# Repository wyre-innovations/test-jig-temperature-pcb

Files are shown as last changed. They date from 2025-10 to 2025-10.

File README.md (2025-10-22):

# STM32G0-based Temperature Test Jig PCB

This repository contains the design and manufacturing files for a temperature test jig PCB based on the STM32G0 microcontroller, featuring a 16×2 LCD and 8 thermistor sensors.

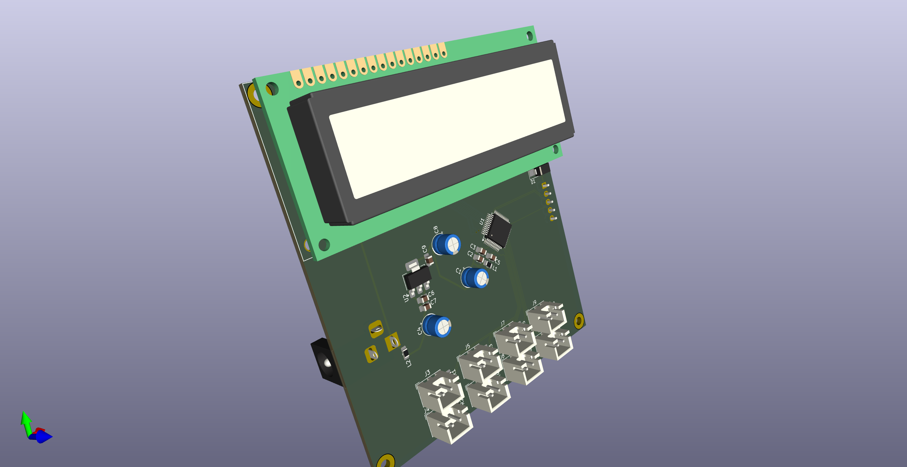
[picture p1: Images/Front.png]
Front View


### Project Structure

The project is organized into the following directories:

- `Design/`: Contains the KiCad design files.
    - `test-jig-temperature-pcb.kicad_pcb`: PCB layout file.
    - `test-jig-temperature-pcb.kicad_pro`: Project file.
    - `test-jig-temperature-pcb.kicad_sch`: Schematic file.
- `Docs/`: Documentation for the project.
    - `Schematic.pdf`: PDF version of the schematic.
- `Images/`: Images related to the project.
    - `Front.png`: Front view image.

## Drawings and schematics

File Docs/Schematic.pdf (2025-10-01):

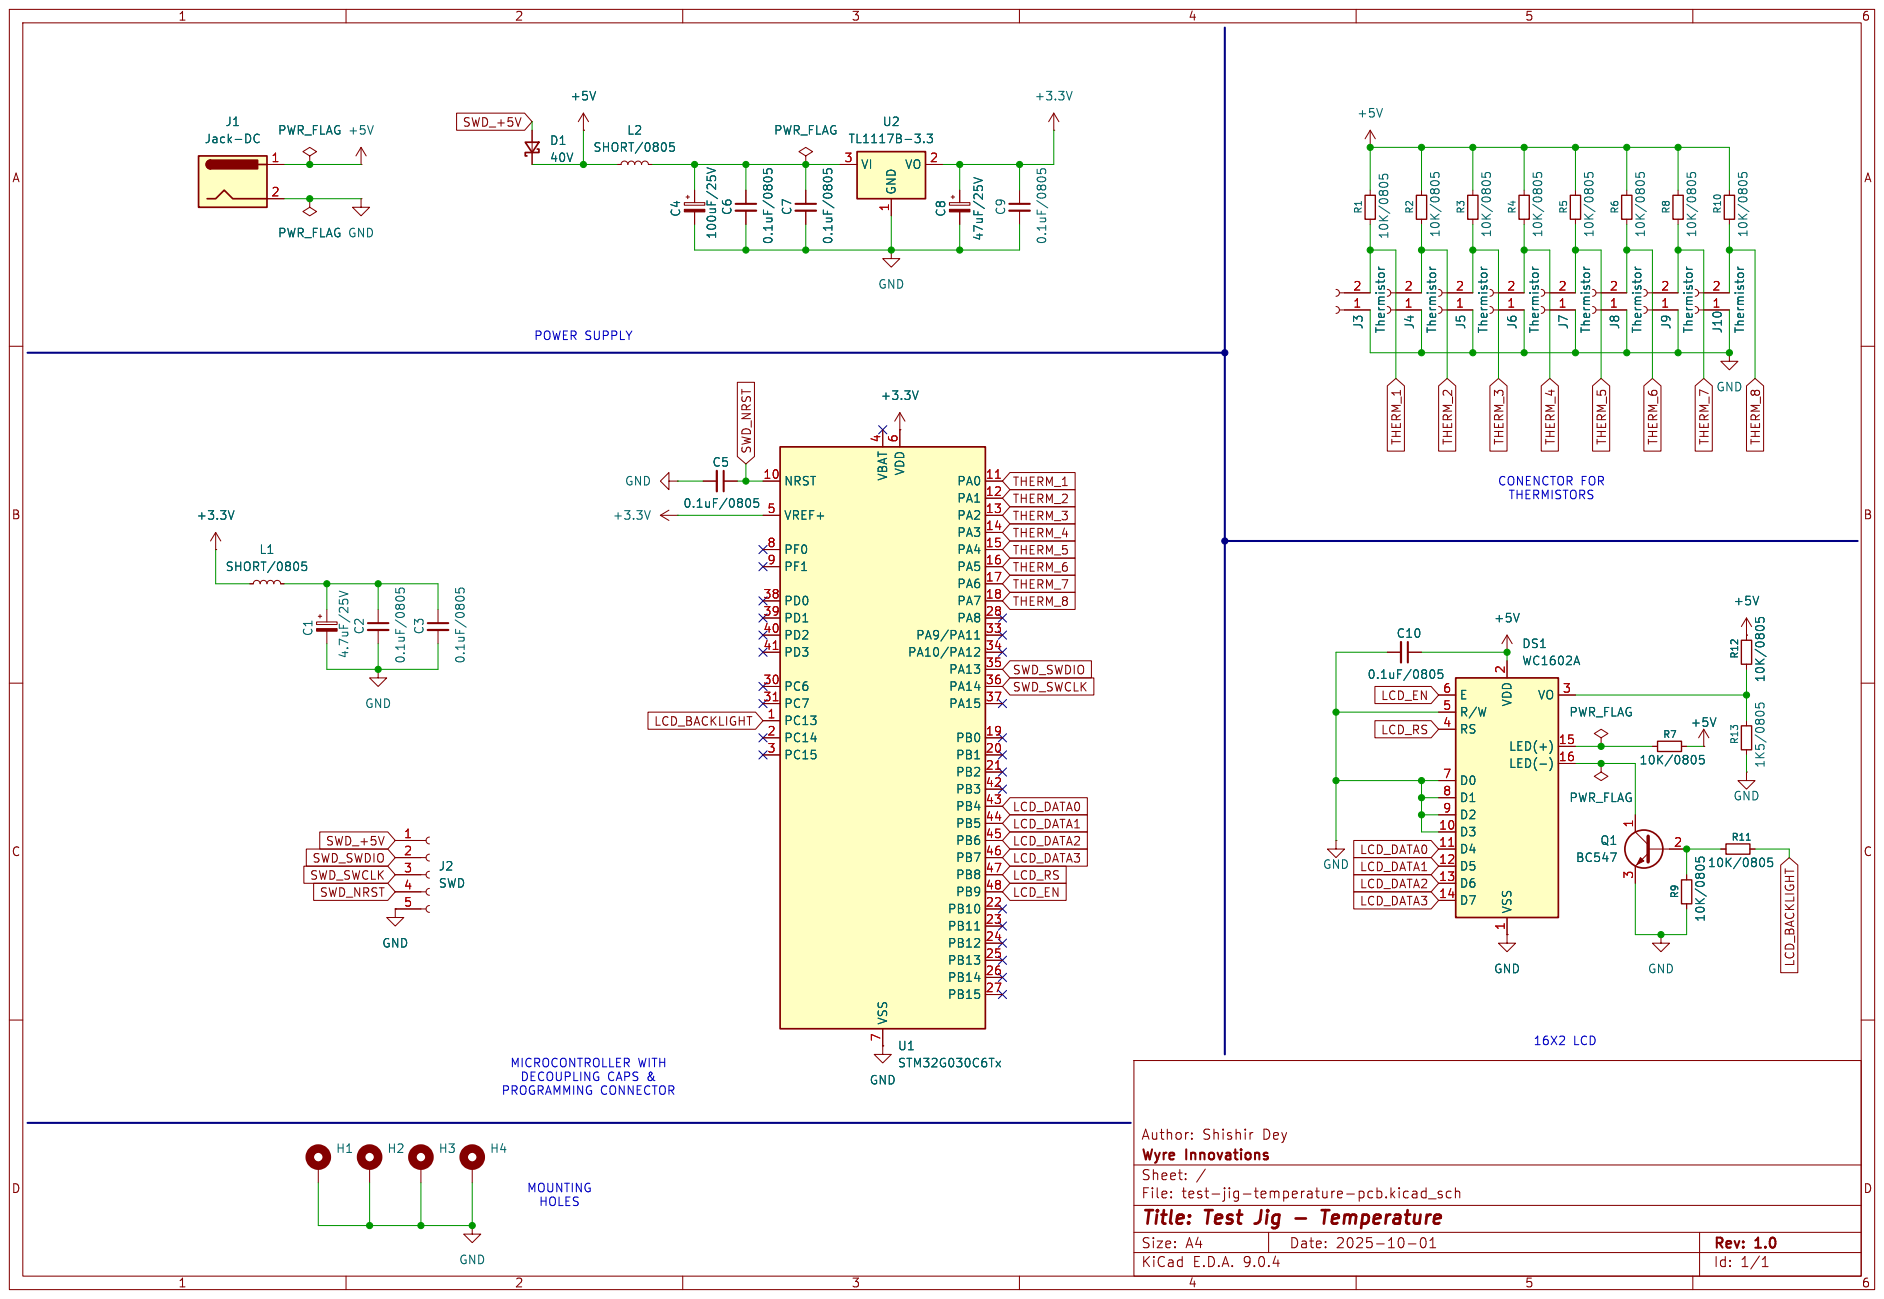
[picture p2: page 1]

Id: 1/1 Title: Test Jig - Temperature

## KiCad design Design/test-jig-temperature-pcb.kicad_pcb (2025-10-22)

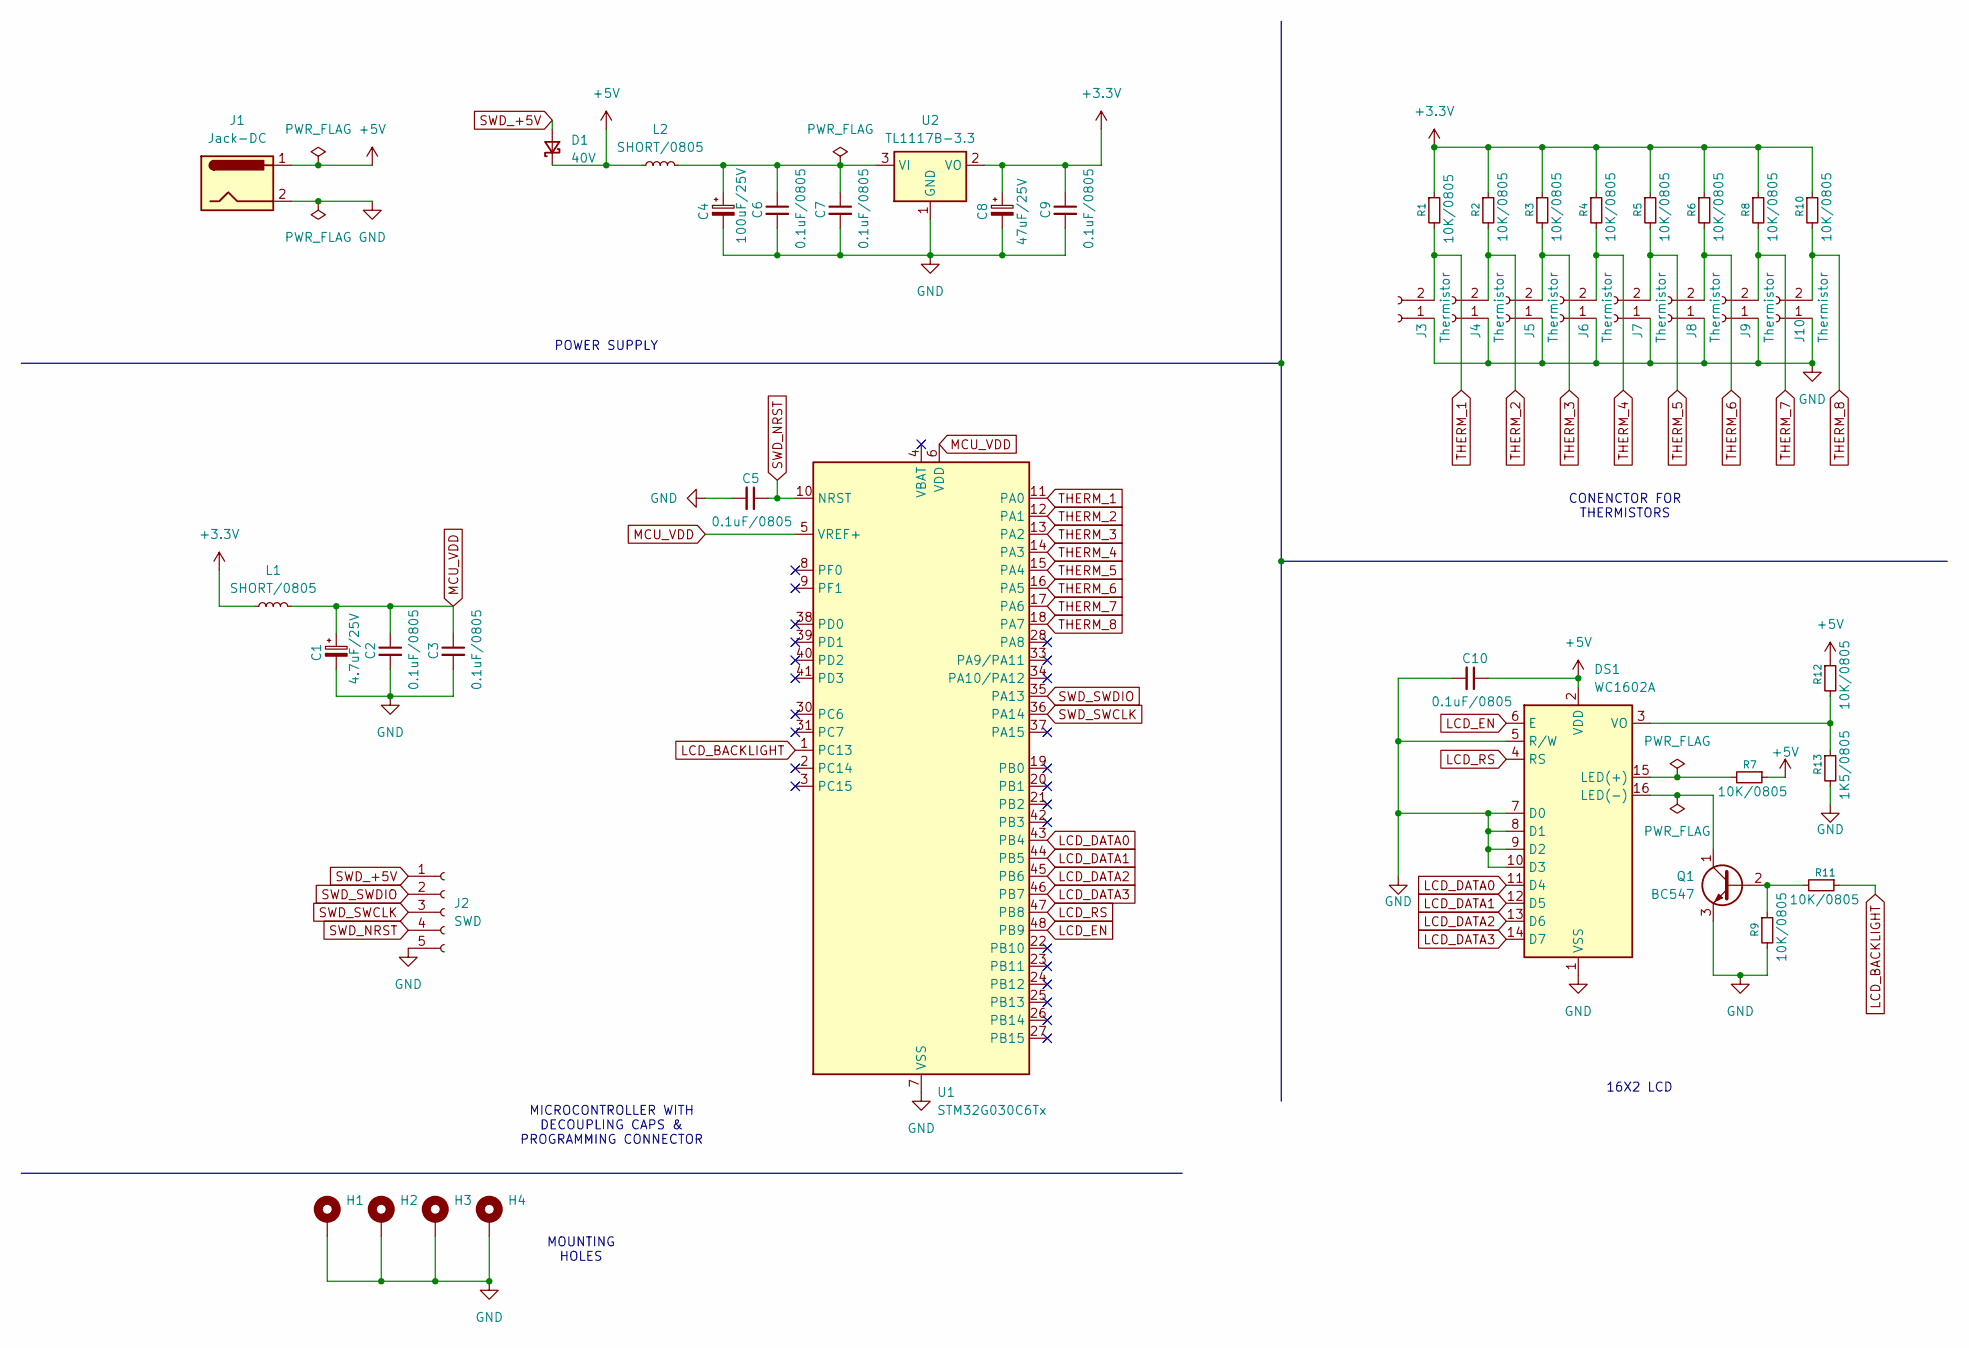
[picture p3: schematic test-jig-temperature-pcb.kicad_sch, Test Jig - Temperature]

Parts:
C1: 4.7uF/25V; CP_Radial_D5.0mm_P2.00mm
C2, C3, C5, C6, C7, C9, C10: 0.1uF/0805; C_0805_2012Metric_Pad1.18x1.45mm_HandSolder
C4: 100uF/25V; CP_Radial_D5.0mm_P2.00mm
C8: 47uF/25V; CP_Radial_D5.0mm_P2.00mm
D1: 40V; D_SMA_Handsoldering
DS1: WC1602A
H1, H2, H3, H4: MOUNTING HOLE; MountingHole_2.5mm_Pad
J1: Jack-DC; BarrelJack_Horizontal
J2: SWD; JST_XH_B5B-XH-A_1x05_P2.50mm_Vertical
J3, J4, J5, J6, J7, J8, J9, J10: Thermistor; JST_XH_B2B-XH-A_1x02_P2.50mm_Vertical
L1, L2: SHORT/0805; R_0805_2012Metric_Pad1.20x1.40mm_HandSolder
Q1: BC547; SOT-23
R1, R2, R3, R4, R5, R6, R7, R8, R9, R10, R11, R12: 10K/0805; R_0805_2012Metric_Pad1.20x1.40mm_HandSolder
R13: 1K5/0805; R_0805_2012Metric_Pad1.20x1.40mm_HandSolder
U1: STM32G030C6Tx; LQFP-48_7x7mm_P0.5mm
U2: TL1117B-3.3; SOT-223-3_TabPin2

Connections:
+3.3V: C8.1, C9.1, L1.1, R1.1, R2.1, R3.1, R4.1, R5.1, R6.1, R8.1, R10.1, U2.2 (VO)
+5V: C10.1, D1.1 (K), DS1.2 (VDD), J1.1, L2.1, R7.1, R12.1
GND: C1.2, C2.2, C3.2, C4.2, C5.2, C6.2, C7.2, C8.2, C9.2, C10.2, DS1.1 (VSS), DS1.5 (R/W), DS1.7 (D0), DS1.8 (D1), DS1.9 (D2), DS1.10 (D3), H1.MP, H2.MP, H3.MP, H4.MP, J1.2, J2.5, J3.1, J4.1, J5.1, J6.1, J7.1, J8.1, J9.1, J10.1, Q1.3 (E), R9.2, R13.2, U1.7 (VSS), U2.1 (GND)
LCD_BACKLIGHT: R11.1, U1.1 (PC13)
LCD_DATA0: DS1.11 (D4), U1.43 (PB4)
LCD_DATA1: DS1.12 (D5), U1.44 (PB5)
LCD_DATA2: DS1.13 (D6), U1.45 (PB6)
LCD_DATA3: DS1.14 (D7), U1.46 (PB7)
LCD_EN: DS1.6 (E), U1.48 (PB9)
LCD_RS: DS1.4 (RS), U1.47 (PB8)
MCU_VDD: C1.1, C2.1, C3.1, L1.2, U1.5 (VREF+), U1.6 (VDD)
unnamed: DS1.15 (LED(+)), R7.2
unnamed: DS1.16 (LED(-)), Q1.1 (C)
unnamed: DS1.3 (VO), R12.2, R13.1
unnamed: Q1.2 (B), R9.1, R11.2
unnamed: C4.1, C6.1, C7.1, L2.2, U2.3 (VI)
SWD_+5V: D1.2 (A), J2.1
SWD_NRST: C5.1, J2.4, U1.10 (NRST)
SWD_SWCLK: J2.3, U1.36 (PA14)
SWD_SWDIO: J2.2, U1.35 (PA13)
THERM_1: J3.2, R1.2, U1.11 (PA0)
THERM_2: J4.2, R2.2, U1.12 (PA1)
THERM_3: J5.2, R3.2, U1.13 (PA2)
THERM_4: J6.2, R4.2, U1.14 (PA3)
THERM_5: J7.2, R5.2, U1.15 (PA4)
THERM_6: J8.2, R6.2, U1.16 (PA5)
THERM_7: J9.2, R8.2, U1.17 (PA6)
THERM_8: J10.2, R10.2, U1.18 (PA7)

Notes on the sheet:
16X2 LCD
MICROCONTROLLER WITH DECOUPLING CAPS & PROGRAMMING CONNECTOR
CONENCTOR FOR THERMISTORS
MOUNTING HOLES
POWER SUPPLY

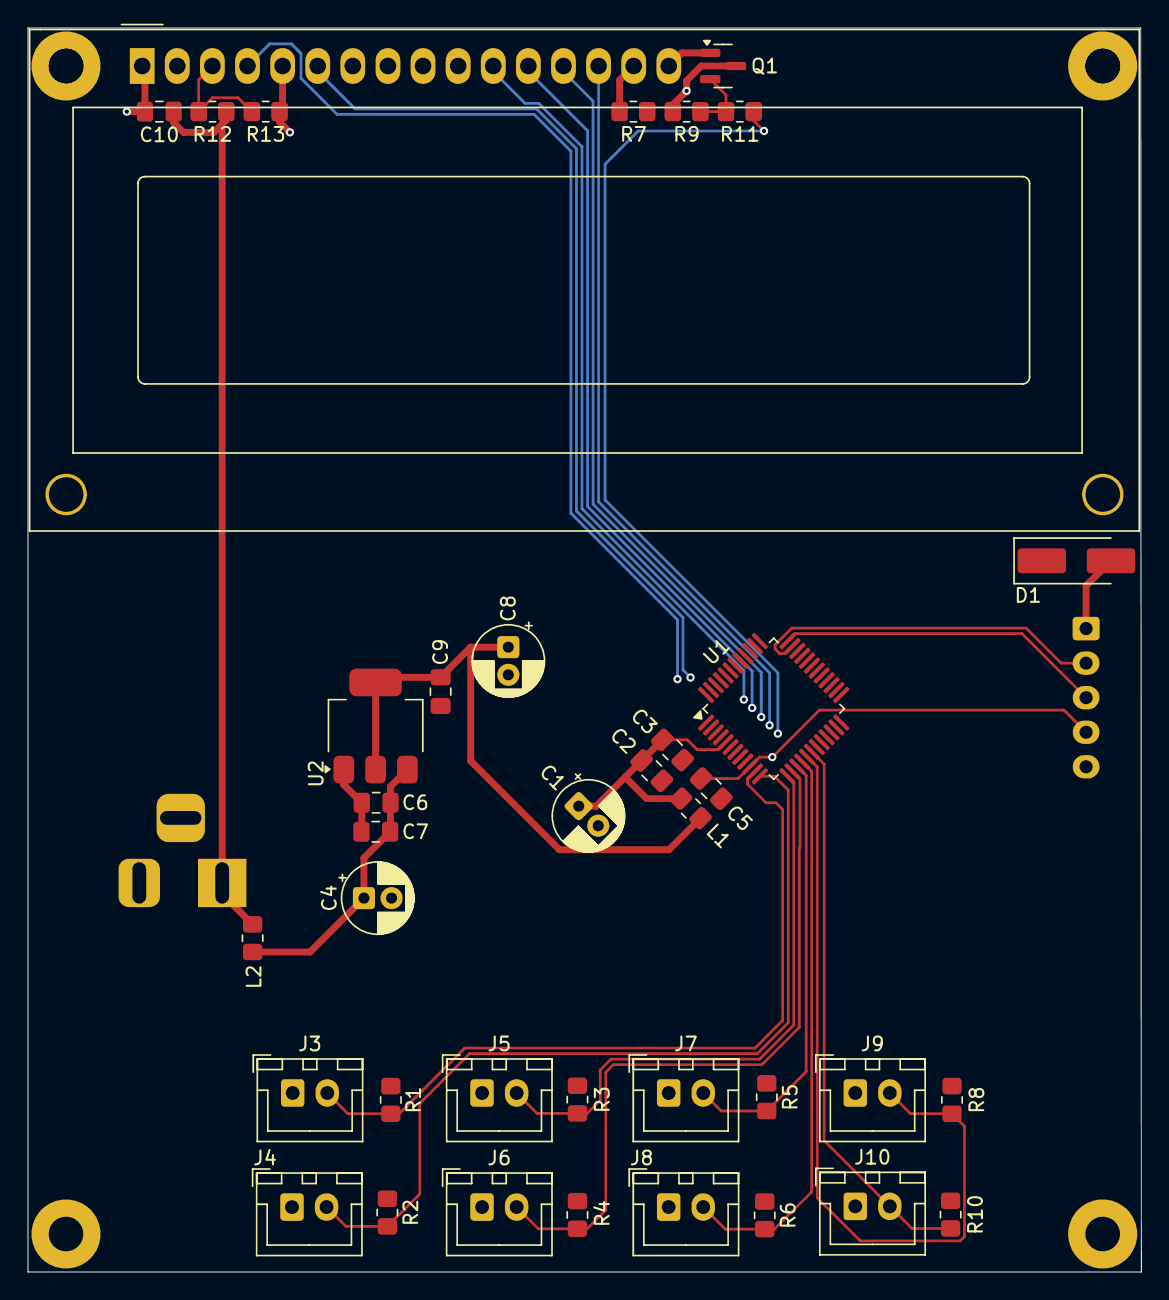
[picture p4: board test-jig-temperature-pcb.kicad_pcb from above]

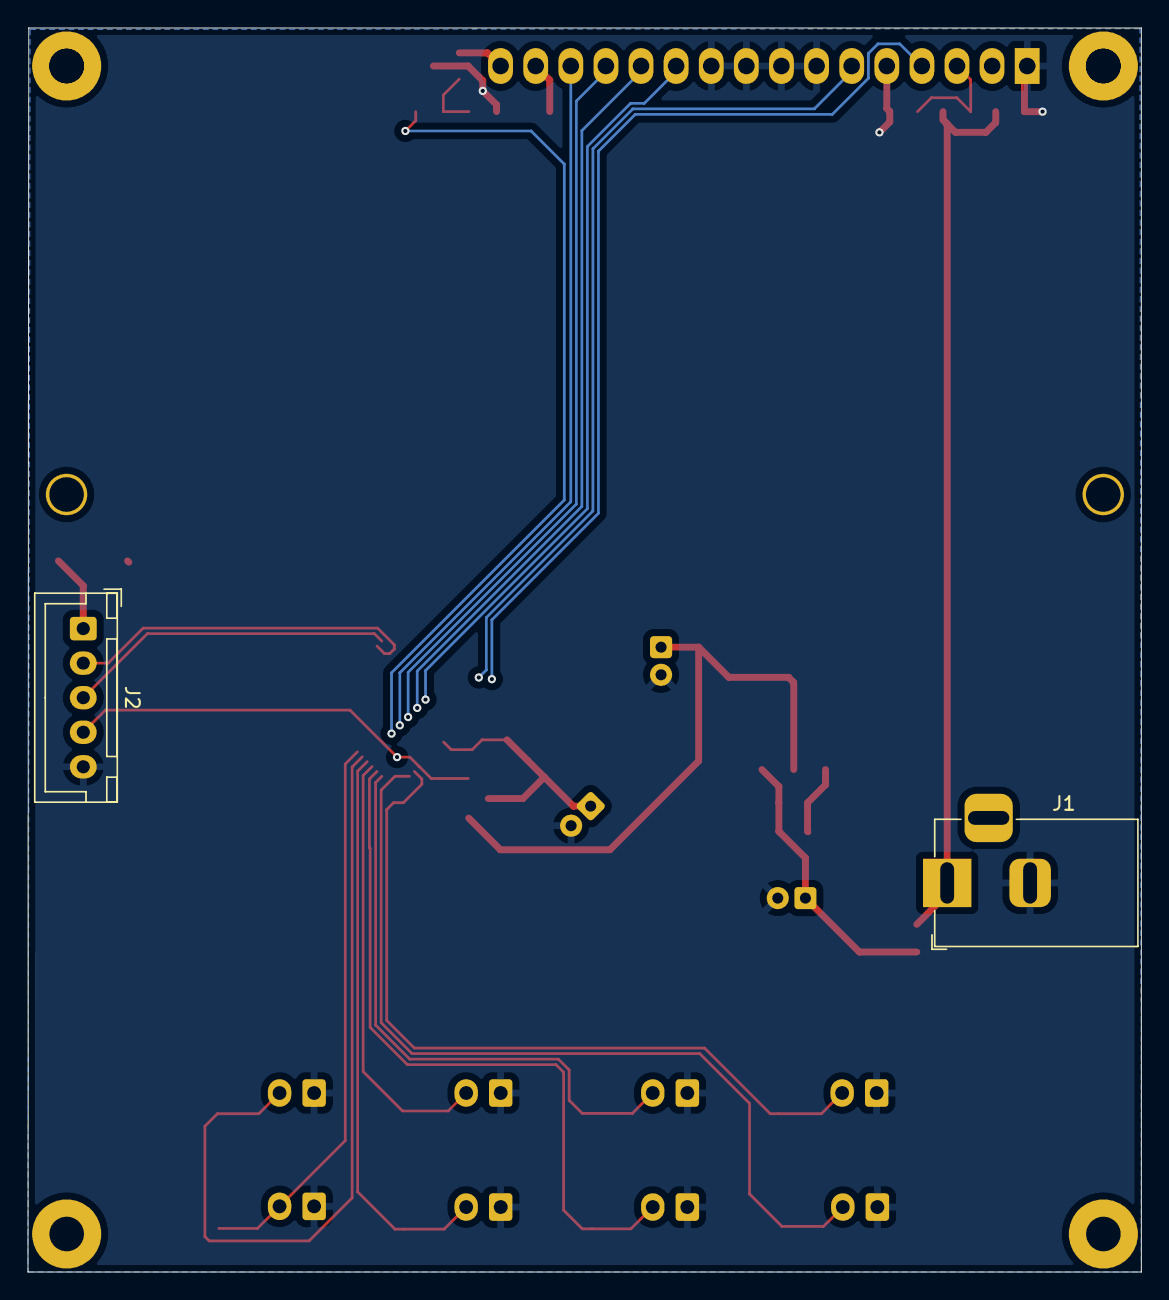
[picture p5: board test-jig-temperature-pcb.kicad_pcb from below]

Board: 2 copper layers, 80.5 x 90.0 mm, 44 parts (2 on the bottom side), 28 nets.

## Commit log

2025-10-01 Add KiCad design files
    [test-jig-temperature-pcb.kicad_pcb, test-jig-temperature-pcb.kicad_sch]
2025-10-01 Add schematic
2025-10-01 Fix ERC issues and re-annotate schematic
    [test-jig-temperature-pcb.kicad_sch]
2025-10-04 Assign footprints to symbols
    [test-jig-temperature-pcb.kicad_pcb, test-jig-temperature-pcb.kicad_sch]
2025-10-20 Group components and route thermistor connector to MCU
    [test-jig-temperature-pcb.kicad_pcb, test-jig-temperature-pcb.kicad_sch]
2025-10-21 Route the 16x2 LCD to the microcontroller
    [test-jig-temperature-pcb.kicad_pcb]
2025-10-21 Reposition thermistor connectors and re-route connections
    [test-jig-temperature-pcb.kicad_pcb, test-jig-temperature-pcb.kicad_sch]
2025-10-22 Route components in power supply section and update README with current PCB image and project structure details
    [test-jig-temperature-pcb.kicad_pcb]
